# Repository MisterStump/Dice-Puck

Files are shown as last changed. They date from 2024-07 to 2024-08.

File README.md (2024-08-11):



# Overview
The goal of this project was to make a little pocket digital dice roller that worked with the standard 7 polyhedral dice used in games like D&D. This GitHub contains the things I purchased, built, or coded. I hope that if anyone else is interested in a project like this, they can use this as a rough guide. Or maybe just provide some insight to anyone interested into some of the challenges I ran into.

## Features
- Select a d4, d6, d8, d10, d12, d20, or d100, as well as how many of them to roll
- Roll the dice and see up to 14 individual results as well as the total
    - More than 14 dice can still be rolled but the individual results are all layers on top of eachother randomly
- Sleep mode to help extend battery life when not in use

## Functionality
The Dice Puck is always on when powered. It has 2 main screens and a sleep mode, all with different controls. Note that you can only roll 1 type of die at a time, and it does not apply any modifiers. The screen will go to sleep after 1 minute without use.
- Mode: Roll Selection
    - Drag up/down = increase/decrease # of dice to roll
    - Drag left/right = change which die type to roll
    - Press and hold  = Reset # of dice to roll to 0
    - Shake = Roll the currently selected die
- Mode: Roll Results
    - Press and hold = return to the Roll Selection screen
- Mode: Sleep
    - Press and hold = wake up

## Parts
There are 3 physical components to this project.

- Purchased Parts
    - ESP32-S3 development board with screen and sensors
        - https://www.waveshare.com/esp32-s3-touch-lcd-1.28.htm
    - Battery: 3.7v - 220mAh - JST PH1.25
        - https://www.amazon.com/dp/B0CHY5NBM2
- Printed Parts
    - Case requires a 3d printer to produce. I used a Prusa Mk3s+

# Development
The journey to create and run this project was involved and I was able to learn a lot. I'll outline my general journey and resources here, if you want to follow a similar path. In the next section I'll outline problems I encountered that you should be aware of if you want to do something similar.

## Image conversion
Getting images into the correct format and size was a pain. I had to save vector graphics (svc), export them into png to set the background color & dimensions, then convert them to jpg using a command line utility called ImageMagik. There are "source.txt" files in the image folders that give a little more detail.

## Font conversion
I used a python script called front2bitmap.py to convert a truetype font (UniversCondened.tff) into a file that MicroPython could render. The font is widely available, but I obtained it here:

> https://online-fonts.com/fonts/univers-condensed

## Coding
I set up this project to code using Thonny/MicroPython. I think the Arduino approach might potentially work better, but I was already familiar with Thonny/MPy. I followed the setup guide in the dev board's wiki:

> https://www.waveshare.com/wiki/ESP32-S3-Touch-LCD-1.28

The walkthrough provides the tools needed to flash board, connect to it with Thonny, etc. Once you do all that, you would use Thonny to upload all of the files/subfolders in the "Program" folder onto the device. Then you would either run "DicePuck.py" from the device, or you would unplug/replug the device.

## Modeling a case
I have done quite a bit with OpenSCAD, so this came together rather well. It is just a hollow shell with a cutout for the screen. Then a plastic "shelf" in the middle that keeps the battery off of the circuit board. If you get a thicker/thinner battery, you'd need to modify the .scad file using the OpenSCAD program's Customizer (or use Thingiverse Customizer [here](https://www.thingiverse.com/thing:6726376) ). No code changes required.

Note: The little cutout notch in the "shelf" goes on the opposite side from the battery connector.

# Problems
I ran across a number of problems during this project, some of which I did not fully solve. If you intend to build this project, or use it as a launchpad for yo
- Battery polarity this board takes is reversed from what seems to be widely available
    - I was able to use tweezers to lift up the little plastic tabs on the battery connector, pull out the wires, and reverse them. It is very small and fiddly but wasn't too bad.
- Battery level indication not solved
    - I found out how to read voltage from the ADR pin for this dev board, but in the MicroPython I could not figure out how to translate it into a charge percentage. This is currently unsolved, but i left my semi-functional library in the 'sensorlib' folder.
- In the MicroPython examples provided in the wiki, they only show how to read either the gyro OR the touch screen, not both at the same time.
    - I was able to solve this issue though once I realized both communicate on the same pin set, so I need to set up the connection to that pin set only once and use it with both sensor types
- Touchscreen is not as intuitive or smooth as modern touchscreens
    - I have spent little or no time refining the code to make for a good user experience. Improvements can be made, but my goal was to deliver minimal functionality with the lowest battery usage I could manage.
- The boot file on the ESP board causes the device to always run, which makes it hard to write to
    - I am able to solve this by just trying to run code from my PC on the thonny which tends to overwrite the automatic boot. But if worse came to worse, I could upload a new boot.py that odesn't autorun any code

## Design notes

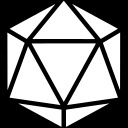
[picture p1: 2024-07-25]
Program/images/d20.jpg

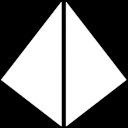
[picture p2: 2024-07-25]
Program/images/d4.jpg

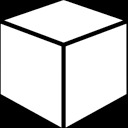
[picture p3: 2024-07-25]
Program/images/d6.jpg

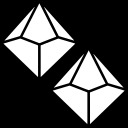
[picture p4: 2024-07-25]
Program/images/d100.jpg

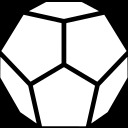
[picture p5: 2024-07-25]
Program/images/d12.jpg

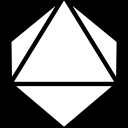
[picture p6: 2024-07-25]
Program/images/d8.jpg

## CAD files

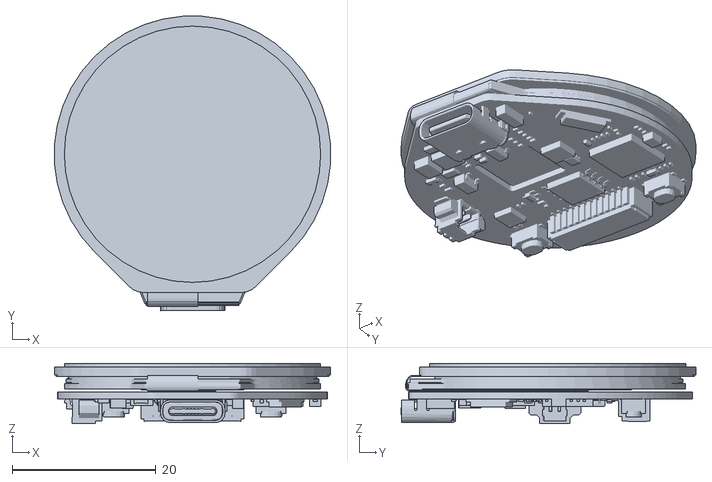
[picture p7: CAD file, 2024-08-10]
Case/ESP32-S3-Touch-LCD-1_28.stl
38.4 x 41.0 x 8.40

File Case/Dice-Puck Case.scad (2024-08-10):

/////////////////////////////
// Parameters
/////////////////////////////

//Which part to print
Part = "All"; //[All,Face,Back,Spacer]
//Thickness of battery
Battery_Thickness = 4.3;
//Extra spacing needed around threads to allow for parts to fit together
Thread_Tollerance = 0.2;
//Extra spacing needed around spacer to allow it to fit in the face
Spacer_Tolerance = 0.2;

module endParams(){}endParams();





/////////////////////////////
// Back-end parameters
/////////////////////////////

$fn = 128;
eps = 0.007;

//thread twists
threadTwists = 0.75;

//Measurements of display screen and its frame
//display is the screen
display_diameter = 35.7;
displayFrame_diameter = 39; //38.6
displayFrame_thickness = 1;
//Nub is the extra bit that sticks out towards USB on the frame
displayNub_x_widest = 25.3;
displayNub_x_widest_rot45 = displayNub_x_widest * sin(45);
displayNub_y_from0 = findTSide(t="b", a=(displayNub_x_widest/2), c=(displayFrame_diameter/2));
displayNub_y_cutoff = displayNub_y_from0 + 7.48;
//faceWall is the walls around the face and circuit board
wallThickness = 6.87/2; // there is prob math for this but its HARD so eff it
faceWall_diameter = displayFrame_diameter + wallThickness*2;
faceWall_depth = 10;
//Wall behind threads
threadWall = 1;
threadHeight = Battery_Thickness;
thread_inner = displayFrame_diameter/2+threadWall;
thread_outer = faceWall_diameter/2-threadWall;

//Measurements for the back piece
back_diameter = faceWall_diameter;
back_thickness = 1;
back_threadHeight = threadHeight;
back_thread_offset = Thread_Tollerance;
back_thread_outer = back_diameter/2-threadWall+back_thread_offset;
back_thread_inner = back_thread_outer - (thread_outer-thread_inner);

//Measurements for the spacer
//This goes in the case between the device and the battery
spacer_thickness = 1;
spacer_diameter = displayFrame_diameter - Spacer_Tolerance;
spacer_height = 4; //may need to be +4?
spacer_width = 2;





/////////////////////////////
// Logic - what gets made
/////////////////////////////

if (Part=="Face"){
    part_face();
}
else if (Part=="Back"){
    part_back();
}
else if (Part=="Spacer"){
    part_spacer();
}
else if (Part=="All"){
    translate([-faceWall_diameter - 5,0,0])
    part_face();
    translate([faceWall_diameter + 5,0,0])
    part_back();
    part_spacer();
}





/////////////////////////////
// Parts - elements of models
/////////////////////////////

//Inner face 2d shape, without a display cutout
module part_2d_face_inner(){
    difference(){
        union(){
            //circle
            circle(d=displayFrame_diameter);
            //Nub
            translate([0,-displayNub_y_from0,0])
            rotate([0,0,45])
            square(displayNub_x_widest_rot45,center=true);
        }
        //cutoff for end of nub
        translate([0,-displayNub_y_cutoff-(displayFrame_diameter/2),0])
        square(displayFrame_diameter, center=true);
    }
}

//Outer face 2d shape, without a display cutout
module part_2d_face_outer(){
    difference(){
        difference(){
            //wall area
            circle(d=faceWall_diameter);
            //center cutout
            part_2d_face_inner();
            //End cutoff at nub
            translate([0,-displayNub_y_cutoff-(displayFrame_diameter/2)+eps,0])
            square(displayFrame_diameter, center=true);
        }
    }
}

//Create the face of the case
module part_face(){
    union(){
        //inner area of the face
        linear_extrude(displayFrame_thickness)
        difference(){
            //face
            part_2d_face_inner();
            //display cutout
            circle(d=display_diameter);
        }

        //outer wall of the face
        linear_extrude(faceWall_depth)
        part_2d_face_outer();
        
        //wall in front of usb
        part_face_usbWall();
        
        //threads
        part_face_threads();
    }
}

//Creates little wall in front of USB on the face
module part_face_usbWall(){
    linear_extrude(faceWall_depth-5)
    intersection(){
        //wall
        translate([0,1/2 - displayNub_y_cutoff,0])
        square([15,1],center=true);
        //cylinder
        circle(d=faceWall_diameter);
    }
}

// Threaded part of the face
module part_face_threads(){
    translate([0,0,faceWall_depth])
    difference(){
        //Threads
        difference(){
            //thread
            printableThread(
                r_int=thread_inner,
                r_ext=thread_outer,
                h=threadHeight,
                twist=-threadTwists,
                tc=2
            );
            //chamfer
            threadChamfer(
                r_int=thread_inner,
                h=threadHeight,
                size=2,
                angle=45,
                edge="top",
                type="subtract"
            );
        }
        //Cutout for middle
        translate([0,0,-eps/2])
        cylinder(d=displayFrame_diameter, h=threadHeight+eps);
        //Cutout for usb nub
        translate([0,0,-eps/2])
        linear_extrude(threadHeight+eps)
        part_2d_face_inner();
        //Cutout for the pointy thread remainder bits
        translate([0,0,-eps/2])
        rotate([0,0,-90-(55/2)])
        rotate_extrude(angle=55)
        translate([displayNub_y_cutoff-threadHeight,0,0])
        square(threadHeight+eps);
    }
}

//Create back part of model
module part_back(){
    difference(){
        //back and walls
        linear_extrude(back_thickness+back_threadHeight)
        circle(d=back_diameter);
        //thread cutout
        translate([0,0,back_thickness+eps]){
            printableThread(
                r_int=back_thread_inner,
                r_ext=back_thread_outer,
                h=back_threadHeight,
                twist=-threadTwists,
                tc=2
            );
            //thread chamfer cutout
            threadChamfer(
                r_int=back_thread_inner,
                h=back_threadHeight,
                size=2,
                angle=45,
                edge="top",
                type="add"
            );
        }
        
    }
}

//Create a peg for the spacer
//A is the # of degrees (out of 360) that the peg's arc takes
//r is the amount of z rotation used to position it around the spacer
module part_spacer_peg(a,r){
    rotate([0,0,r])
    rotate_extrude(angle=a)
    translate([spacer_diameter/2-spacer_width,0,0])
    square([spacer_width,spacer_height]);
}

// Create spacer
module part_spacer(){
    //translate([0,0,10])
    //rotate([0,180,0])
    translate([0,0,spacer_thickness])
    difference(){
        //Spacer
        union(){
            //Plate
            translate([0,0,-spacer_thickness])
            linear_extrude(spacer_thickness)
            circle(d=spacer_diameter);
            //Pegs start with the big one opposite of the USB and go clockwise
            part_spacer_peg(60,60);
            part_spacer_peg(20,145);
            part_spacer_peg(20,198);
            part_spacer_peg(20,198);
            part_spacer_peg(10,245);
            part_spacer_peg(7,304);
            part_spacer_peg(10,337);
            part_spacer_peg(10,376);
        }
        //Notch cutout for power cord
        translate([spacer_diameter/2,0,0])
        cube(5,center=true);
    }
    *
    color([0.6,0.6,0.6])
    translate([0,0,-7])
    rotate([0,180,0])
    import("ESP32-S3-Touch-LCD-1_28.stl");
}





/////////////////////////////
// Helpers - extra libraries and functions
/////////////////////////////

//Find the requested side given either 2 sides or 1 side + 1 angle
//Only works for right triangles
//t must be "a", "b", or "c"
//This is a new func I made for this project because I was tied of dealing with triangle math
//Haven't tested all the variations
function findTSide(t,a=0,b=0,c=0,A=0, B=0) =
    //2 legs known
    a!=0 && b!=0 ? (
        t=="c" ? sqrt(pow(a,2)+pow(b,2)) :
        undef
    ):
    //1 leg (a) and hypotenuse known
    a!=0 && c!=0 ? (
        t=="b" ? sqrt(pow(c,2)-pow(a,2)) :
        undef
    ):
    //1 leg (b) and hypotenuse known
    b!=0 && c!=0 ? (
        t=="a" ? sqrt(pow(c,2)-pow(a,2)) :
        undef
    ):
    //1 leg (a) and opposite angle known
    a!=0 && A!=0 ? (
        t=="b" ? a * tan(90-A) :
        t=="c" ? sqrt(pow(a,2)+pow(a*tan(90-A),2)) :
        undef
    ):
    //1 leg (b) and opposite angle known
    b!=0 && B!=0 ? (
        t=="a" ? b * tan(90-B) :
        t=="c" ? sqrt(pow(b,2)+pow(b*tan(90-B),2)) :
        undef
    ):
    //1 leg (a) and adjacent angle known
    a!=0 && B!=0 ? (
        t=="b" ? a * tan(B):
        t=="c" ? sqrt(pow(a,2)+pow(a*tan(B),2)):
        undef
    ):
    //1 leg (b) and adjacent angle known
    b!=0 && A!=0 ? (
        t=="a" ? b * tan(A):
        t=="c" ? sqrt(pow(b,2)+pow(b*tan(A),2)):
        undef
    ):
    //None found
    undef;
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

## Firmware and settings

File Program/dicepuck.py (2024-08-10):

from random import randint # Random numbers
from machine import Pin, SoftI2C, SPI # ESP board
from sensorlib import cst816, qmi8658, battery # touch/spacial/battery sensors
import gc9a01 # Display
import time # sleep
from data import dice # info about dice
# Fonts
from truetype import UniversCondensed_32 as uni_32
from truetype import UniversCondensed_48 as uni_48
from truetype import UniversCondensed_64 as uni_64

debugMode = False

################################
# Global variables
################################
# Colors for UI (rgb 255)
c = {
    "primary": gc9a01.color565(255,255,255),
    "emphasis": gc9a01.color565(255,255,0),
    "background" : gc9a01.color565(0,0,0),
    "good roll": gc9a01.color565(0,255,0),
    "bad roll": gc9a01.color565(255,0,0)
}
# Time before screen goes into sleep mode (Seconds)
screenTimeout = 30
# Distance travel to trigger a swipe action
swipeSensitivity = 40
# How hard any axis needs to be shaken to trigger a shake action
shakeSensitivity = 200 #400
# Current stage. "rollSetup", "rollResult"
stage = "rollSetup" #"rollSetup"
# Set up common bus for sensors
sensorBus = SoftI2C(scl=Pin(7),sda=Pin(6),freq=100000)
# Establish connections to hardware elements
display = gc9a01.GC9A01( #screen
    SPI(2, baudrate=80000000, polarity=0, sck=Pin(10), mosi=Pin(11)),
    240,
    240,
    reset=Pin(14, Pin.OUT),
    cs=Pin(9, Pin.OUT),
    dc=Pin(8, Pin.OUT),
    backlight=Pin(2, Pin.OUT),
    rotation=0)
display.init()
spacial = qmi8658.QMI8658(sensorBus) #gyro/accel
touch = cst816.CST816(sensorBus) #touchscreen
battery = battery.BATTERY()


################################
# Main function
################################
   
def main():
    #display.fill(c["primary"])
    #return
    
    # Primary loop, runs as long as device is on
    while True:
        # Each "stage" is a screen the user interacts with
        # Select die and die count
        if stage=="rollSetup":
            stage_rollSetup()
        # Show results of roll
        if stage=="rollResult":
            stage_rollResult()












################################
# Stage functions (each is a different "screen" of the dice puck
################################     
        
def stage_rollSetup():
    """Draw and run the roll setup screen"""
    # Draw initial screen
    draw_rollSetup_all()
    #Used to track if a gesture is made by the user, only 1 gesture can be made per press
    gestureFlag = False 
    # Used to detect how many frames the screen has been pressed (used to skip first screen and long press)
    i_press = 0
    # Tracking for sleep
    i_loop = 0
    asleep = False

    while True:
        if asleep:
            # Sleep, watching to be awoken
            time.sleep(1)
            if touch.get_touch():
                i_press = 0
                asleep = False
                display.sleep_mode(False)
                display.on()
                time.sleep(1)
                continue
            else:
                continue
        else:
            # Not asleep, add small delay to save battery
            time.sleep(0.05)
        
        #Battery debugging
        if debugMode:
            display.write(uni_32, str(battery.rawAnalog()), 20, 100, c["primary"], c["background"])
            display.write(uni_32, str(battery.getLevel()), 20, 140, c["primary"], c["background"]) 
        
        # Collect gyro data
        xyz = [abs(i) for i in spacial.Read_XYZ()] # absolute values (no negatives)
        
        # Collect touchscreen data
        #touch = cst816.CST816()
        #point = touch.get_point()
        press = touch.get_touch()
        distance = touch.get_distance()
        
        # Enable sleep mode if screen is not used for 30 seconds
        if not press:
            i_loop += 1
            if i_loop >= screenTimeout / 0.05:
                i_loop = 0
                asleep = True
                display.sleep_mode(True)
                display.off()
                continue
        elif i_loop is not 0:
            i_loop = 0
        
        # Count frames where button is pressed
        # Also causes the first frame to be skipped
        # This is to avoid a bug where "distance" isn't reset from the last press yet
        if press:
            i_press += 1
        elif i_press is not 0:
            i_press = 0
        if i_press == 1:
            continue

        # Reset gesture flag if it isn't already
        if not press and gestureFlag:
            gestureFlag = False
        # If a gesture hasn't been captured yet, check for one
        elif not gestureFlag:
            # Long press
            if i_press >= 1.5 / 0.05:
                #print("Long press", i_press)
                dice.data[dice.i]["count"] = 1
                draw_rollSetup_text()
                gestureFlag = True
            # Swipe right
            if distance.x_dist >= swipeSensitivity:
                #print("Swipe Right", distance.x_dist)
                dice.i = wrapDiceIndex(dice.i - 1)
                draw_rollSetup_all()
                gestureFlag = True
            # Swipe left
            elif distance.x_dist <= -swipeSensitivity:
                #print("Swipe Left", distance.x_dist)
                dice.i = wrapDiceIndex(dice.i + 1)
                draw_rollSetup_all()
                gestureFlag = True
            # Swipe down
            elif distance.y_dist >= swipeSensitivity:
                #print("Swipe Down", distance.y_dist)
                dice.data[dice.i]["count"] += 1
                draw_rollSetup_text()
                gestureFlag = True
            # Swipe up
            elif distance.y_dist <= -swipeSensitivity:
                #print("Swipe Up", distance.y_dist)
                dice.data[dice.i]["count"] -= 1
                if dice.data[dice.i]["count"] < 1:
                    dice.data[dice.i]["count"] = 1
                draw_rollSetup_text()
                gestureFlag = True
        
        # Shake detection
        # Shaking initiates a roll, so this breaks out of rollSetup
        # Disabled IF requires press, and catches gyro in any direction
        #if press and (xyz[3] > shakeSensitivity or xyz[4] > shakeSensitivity or xyz[5] > shakeSensitivity):
        #print(round(xyz[3],0), round(xyz[4],0), round(xyz[5],0))
        if xyz[4] > shakeSensitivity:
            #print(xyz[3],xyz[4],xyz[5])
            global stage
            stage = "rollResult"
            break
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

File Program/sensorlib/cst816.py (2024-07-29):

# SPDX-FileCopyrightText: Copyright (c) 2023 NeoStormer
#
# SPDX-License-Identifier: MIT
"""
`cst816`
================================================================================

CircuitPython driver for the CST816 capacitive touch screen IC


* Author(s): NeoStormer

Implementation Notes
--------------------

**Hardware:**

* `CST816 High Performance Self-Capacitance Touchchip
  <https://www.buydisplay.com/download/ic/DS-CST816S_DS_V1.3.pdf>`_

**Software and Dependencies:**

* Adafruit CircuitPython firmware for the supported boards:
  https://circuitpython.org/downloads

# * Adafruit's Bus Device library: https://github.com/adafruit/Adafruit_CircuitPython_BusDevice
"""

import time
from micropython import const
from machine import Pin

__version__ = "0.0.0+auto.0"
__repo__ = "https://github.com/NeoStormer/CircuitPython_CST816.git"

# I2C ADDRESS
_CST816_ADDR = const(0x15)

# Register Addresses
_CST816_GestureID = const(0x01)
_CST816_FingerNum = const(0x02)
_CST816_XposH = const(0x03)
_CST816_XposL = const(0x04)
_CST816_YposH = const(0x05)
_CST816_YposL = const(0x06)

_CST816_ChipID = const(0xA7)
_CST816_ProjID = const(0xA8)
_CST816_FwVersion = const(0xA9)
_CST816_MotionMask = const(0xAA)

_CST816_BPC0H = const(0xB0)
_CST816_BPC0L = const(0xB1)
_CST816_BPC1H = const(0xB2)
_CST816_BPC1L = const(0xB3)

_CST816_IrqPluseWidth = const(0xED)
_CST816_NorScanPer = const(0xEE)
_CST816_MotionSlAngle = const(0xEF)
_CST816_LpScanRaw1H = const(0xF0)
_CST816_LpScanRaw1L = const(0xF1)
_CST816_LpScanRaw2H = const(0xF2)
_CST816_LpScanRaw2L = const(0xF3)
_CST816_LpAutoWakeTime = const(0xF4)
_CST816_LpScanTH = const(0xF5)
_CST816_LpScanWin = const(0xF6)
_CST816_LpScanFreq = const(0xF7)
_CST816_LpScanIdac = const(0xF8)
_CST816_AutoSleepTime = const(0xF9)
_CST816_IrqCtl = const(0xFA)
_CST816_AutoReset = const(0xFB)
_CST816_LongPressTime = const(0xFC)
_CST816_IOCtl = const(0xFD)
_CST816_DisAutoSleep = const(0xFE)

# Modes
_CST816_Point_Mode = const(1)
_CST816_Gesture_Mode = const(2)
_CST816_ALL_Mode = const(3)

# Gestures
_CST816_Gesture_None = const(0)
_CST816_Gesture_Up = const(1)
_CST816_Gesture_Down = const(2)
_CST816_Gesture_Left = const(3)
_CST816_Gesture_Right = const(4)
_CST816_Gesture_Click = const(5)
_CST816_Gesture_Double_Click = const(11)
_CST816_Gesture_Long_Press = const(12)


class CST816:
    """Driver for the CST816 Touchscreen connected over I2C."""

    def __init__(self, commonBus):
        self.i2c_device = commonBus
        self.prev_x = 0
        self.prev_y = 0
        self.prev_touch = False
        self.x_point = 0
        self.y_point = 0
        self.x_dist = 0
        self.y_dist = 0
        self.mode = 0
                
        self.rst=Pin(13,Pin.OUT)

        self.reset()
        self.stop_sleep()

    def _i2c_write(self, reg, value):
        """Write to I2C"""
        self.i2c_device.writeto(_CST816_ADDR,bytes([reg, value]))

    def _i2c_read(self, reg):
        """Read from I2C"""
        data = bytearray(1)
        self.i2c_device.readfrom_mem_into(_CST816_ADDR,int(reg), data)
        return data[0]

    def who_am_i(self):
        """Check the Chip ID"""
        return bool(self._i2c_read(_CST816_ChipID) == 0xB5)

    def reset(self):
        """Make the Chip Reset"""
        self.rst(0)
        time.sleep_ms(1)
        self.rst(1)
        time.sleep_ms(50)

    def read_revision(self):
        """Read Firmware Version"""
        return self._i2c_read(_CST816_FwVersion)

    def wake_up(self):
        """Make the Chip Wake Up"""
        self._i2c_write(_CST816_DisAutoSleep, 0x00)
        time.sleep(0.01)
        self._i2c_write(_CST816_DisAutoSleep, 0x01)
        time.sleep(0.05)
        self._i2c_write(_CST816_DisAutoSleep, 0x01)

    def stop_sleep(self):
        """Make the Chip Stop Sleeping"""
        self._i2c_write(_CST816_DisAutoSleep, 0x01)

    def set_mode(self, mode):
        """Set the Behaviour Mode"""
        if mode == _CST816_Point_Mode:
            self._i2c_write(_CST816_IrqCtl, 0x41)
        elif mode == _CST816_Gesture_Mode:
            self._i2c_write(_CST816_IrqCtl, 0x11)
            self._i2c_write(_CST816_MotionMask, 0x01)
        else:
            self._i2c_write(_CST816_IrqCtl, 0x71)
        self.mode = mode

    def get_point(self):
        """Get the Pointer Position"""
        x_point_h = self._i2c_read(_CST816_XposH)
        x_point_l = self._i2c_read(_CST816_XposL)
        y_point_h = self._i2c_read(_CST816_YposH)
        y_point_l = self._i2c_read(_CST816_YposL)
        self.x_point = ((x_point_h & 0x0F) << 8) + x_point_l
        self.y_point = ((y_point_h & 0x0F) << 8) + y_point_l
        return self

    def get_gesture(self):
        """Get the Gesture made by the User"""
        gesture = self._i2c_read(_CST816_GestureID)
        return gesture

    def get_touch(self):
        """Detect User Presence, are they touching the screen?"""
        finger_num = self._i2c_read(_CST816_FingerNum)
        return finger_num > 0

    def get_distance(self):
        """Get the Distance made Between Readings, only while touched"""
        touch_data = self.get_point()
        x = touch_data.x_point
        y = touch_data.y_point
        if self.prev_touch is False and self.get_touch() is True:
            self.x_dist = 0
            self.y_dist = 0
        else:
            self.x_dist = x - self.prev_x
            self.y_dist = y - self.prev_y
        self.prev_touch = self.get_touch()
        self.prev_x = x
        self.prev_y = y
        return self
